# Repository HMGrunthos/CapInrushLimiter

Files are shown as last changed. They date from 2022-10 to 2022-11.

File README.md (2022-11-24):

# CapInrushLimiter
Inspiration:
* [This answer](https://electronics.stackexchange.com/questions/80365/capacitor-inrush-current/80428#80428)
* [And this question](https://electronics.stackexchange.com/questions/163939/inrush-current-limiter-design-questions-review)

Schematics:
* [Model schematic](ModelSchematic.pdf)
* [PCB schematic](CapInrushLimBB/CapInrushLimiter.pdf)

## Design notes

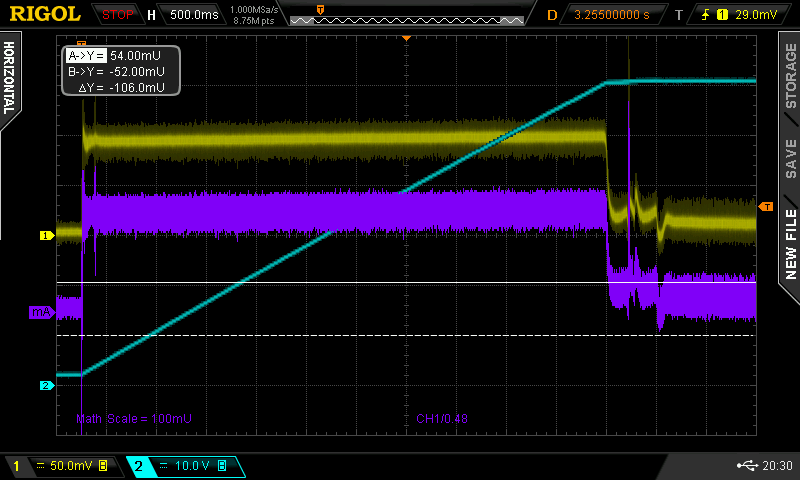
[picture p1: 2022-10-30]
ScopeTraces/RevOneCharge60V.png

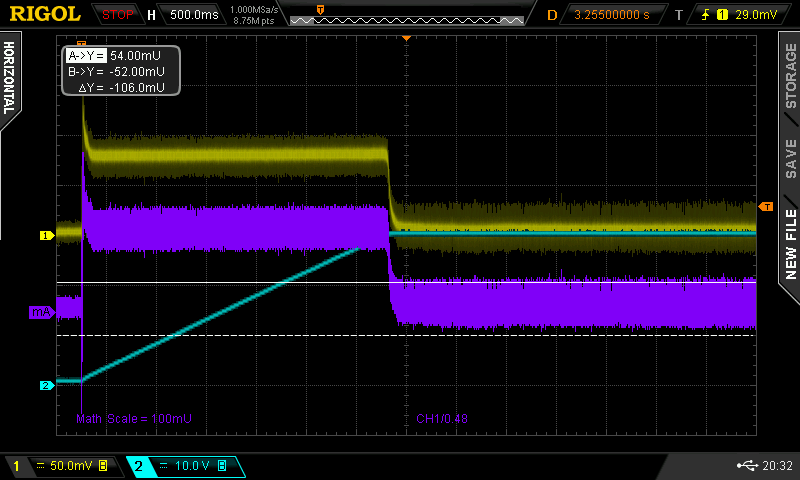
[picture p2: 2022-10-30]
ScopeTraces/RevOneCharge30V.png

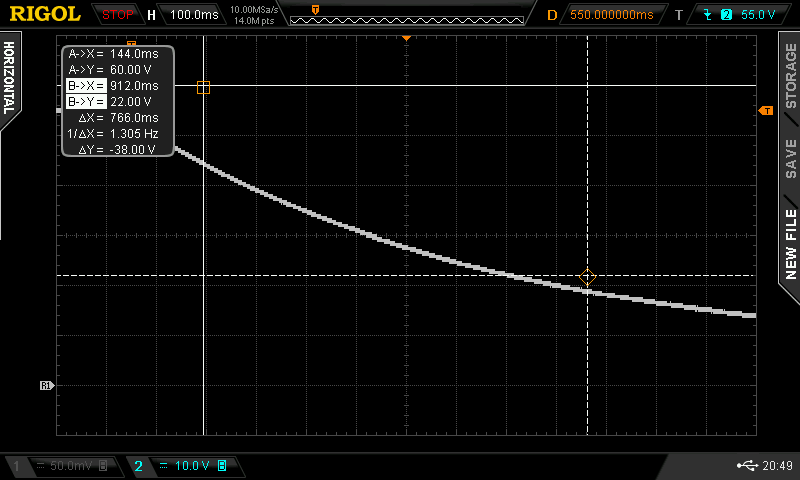
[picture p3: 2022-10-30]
ScopeTraces/RevOneDischargeThrough46R96.png

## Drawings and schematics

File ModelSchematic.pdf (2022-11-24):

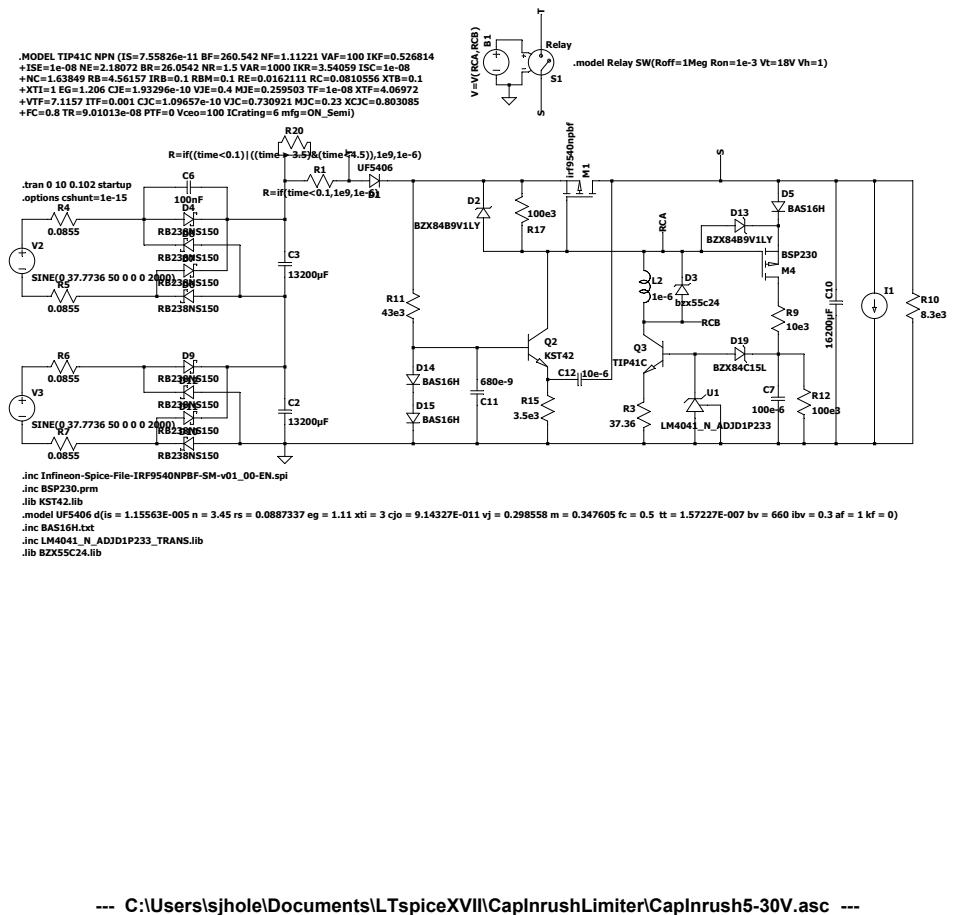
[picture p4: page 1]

Relay
.model Relay SW(Roff=1Meg Ron=1e-3 Vt=18V Vh=1)

.MODEL TIP41C NPN (IS=7.55826e-11 BF=260.542 NF=1.11221 VAF=100 IKF=0.526814
+ISE=1e-08 NE=2.18072 BR=26.0542 NR=1.5 VAR=1000 IKR=3.54059 ISC=1e-08
+NC=1.63849 RB=4.56157 IRB=0.1 RBM=0.1 RE=0.0162111 RC=0.0810556 XTB=0.1
+XTI=1 EG=1.206 CJE=1.93296e-10 VJE=0.4 MJE=0.259503 TF=1e-08 XTF=4.06972
+VTF=7.1157 ITF=0.001 CJC=1.09657e-10 VJC=0.730921 MJC=0.23 XCJC=0.803085
+FC=0.8 TR=9.01013e-08 PTF=0 Vceo=100 ICrating=6 mfg=ON_Semi)

R=if((time<0.1)|((time > 3.5)&(time<4.5)),1e9,1e-6)

.inc Infineon-Spice-File-IRF9540NPBF-SM-v01_00-EN.spi
.inc BSP230.prm
.lib KST42.lib
.model UF5406 d(is = 1.15563E-005 n = 3.45 rs = 0.0887337 eg = 1.11 xti = 3 cjo = 9.14327E-011 vj = 0.298558 m = 0.347605 fc = 0.5 tt = 1.57227E-007 bv = 660 ibv = 0.3 af = 1 kf = 0)
.inc BAS16H.txt
.inc LM4041_N_ADJD1P233_TRANS.lib
.lib BZX55C24.lib

--- C:\Users\sjhole\Documents\LTspiceXVII\CapInrushLimiter\CapInrush5-30V.asc ---

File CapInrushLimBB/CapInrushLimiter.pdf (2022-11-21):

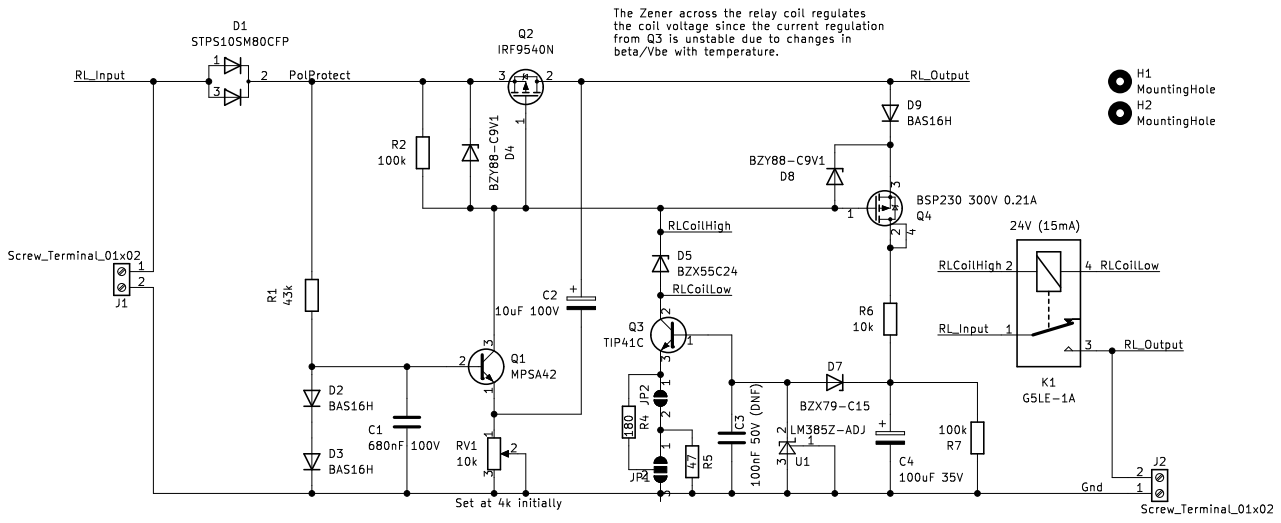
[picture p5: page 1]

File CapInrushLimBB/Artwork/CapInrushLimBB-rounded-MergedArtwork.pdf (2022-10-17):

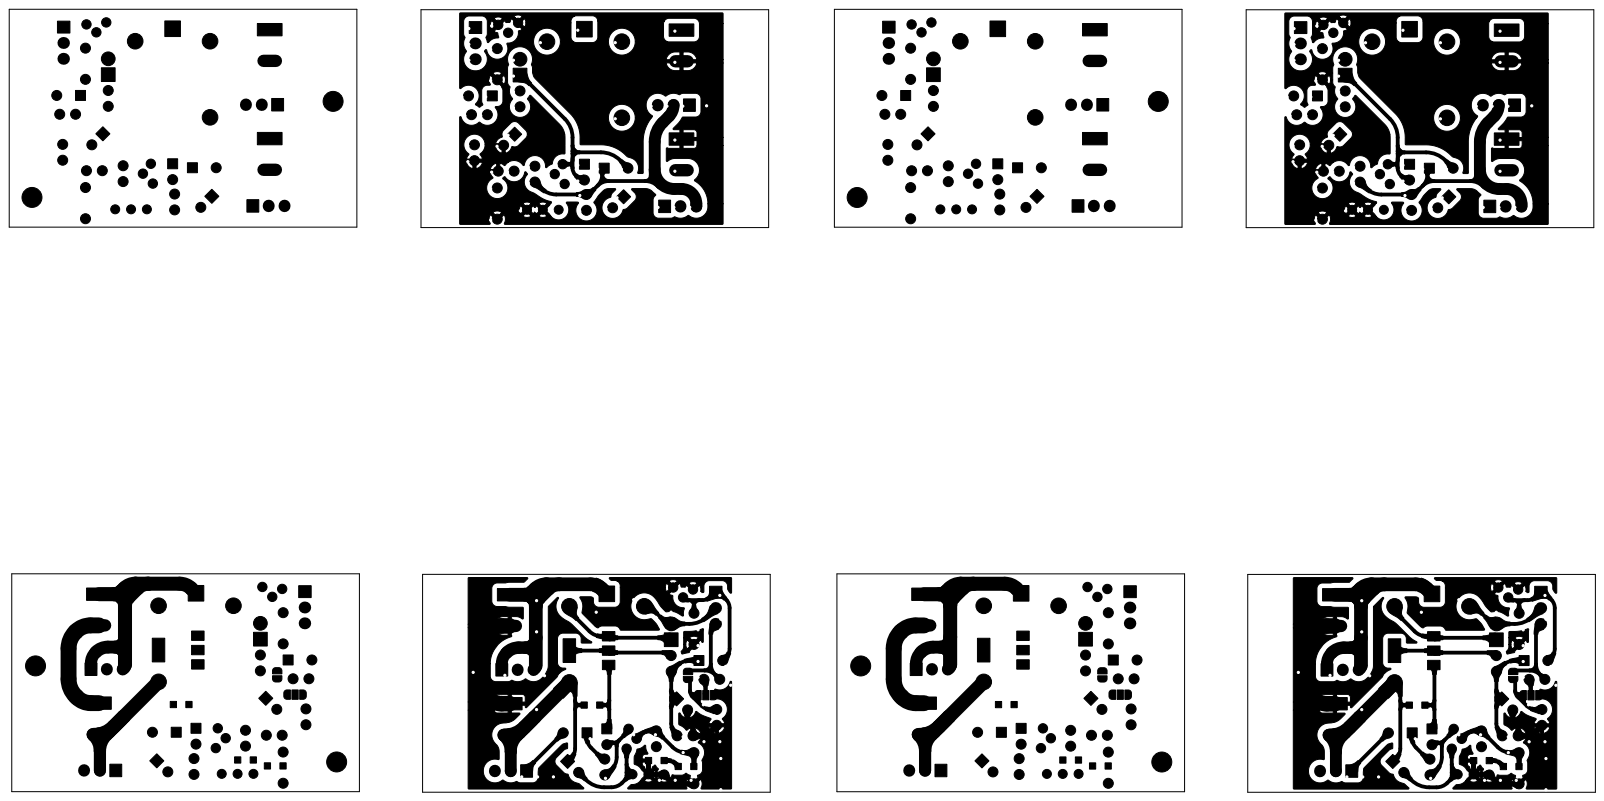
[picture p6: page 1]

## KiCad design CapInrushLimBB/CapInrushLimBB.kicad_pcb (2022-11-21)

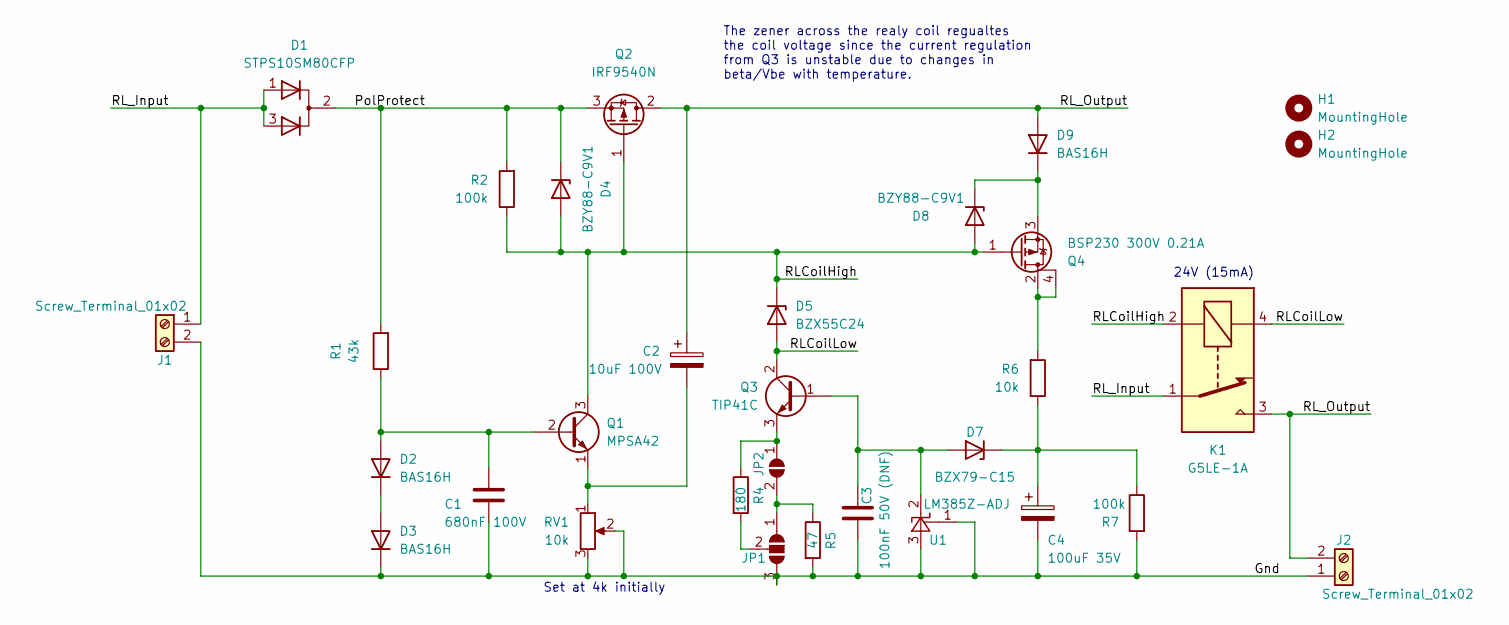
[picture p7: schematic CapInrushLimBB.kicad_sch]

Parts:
C1: 680nF 100V; C_Disc_D5.1mm_W3.2mm_P5.00mm
C2: 10uF 100V; CP_Radial_D6.3mm_P2.50mm
C3: 100nF 50V (DNF); C_Disc_D5.1mm_W3.2mm_P5.00mm
C4: 100uF 35V; CP_Radial_D6.3mm_P2.50mm
D1: STPS10SM80CFP; TO-220F-3_Vertical
D2, D3, D9: BAS16H; D_SOD-323_HandSoldering
D4: BZY88-C9V1; D_DO-35_SOD27_P3.81mm_Vertical_AnodeUp
D5: BZX55C24; D_DO-35_SOD27_P2.54mm_Vertical_KathodeUp
D7: BZX79-C15; D_DO-35_SOD27_P3.81mm_Vertical_AnodeUp
D8: BZY88-C9V1; D_DO-35_SOD27_P2.54mm_Vertical_AnodeUp
H1, H2: MountingHole; MountingHole_3.2mm_M3
J1, J2: Screw_Terminal_01x02; TerminalBlock_Altech_AK300-2_P5.00mm
JP1: SolderJumper_3_Open; SolderJumper-3_P1.3mm_Open_RoundedPad1.0x1.5mm
JP2: SolderJumper_2_Open; SolderJumper-2_P1.3mm_Open_RoundedPad1.0x1.5mm
K1: G5LE-1A; Relay_SPST-NO_Omron-G5LE-1A
Q1: MPSA42; TO-92_Inline
Q2: IRF9540N; TO-220-3_Vertical
Q3: TIP41C; TO-220-3_Vertical
Q4: BSP230 300V 0.21A; SOT-223
R1: 43k; R_Axial_DIN0207_L6.3mm_D2.5mm_P2.54mm_Vertical
R2, R7: 100k; R_Axial_DIN0207_L6.3mm_D2.5mm_P2.54mm_Vertical
R4: 180; R_Axial_DIN0207_L6.3mm_D2.5mm_P2.54mm_Vertical
R5: 47; R_Axial_DIN0207_L6.3mm_D2.5mm_P2.54mm_Vertical
R6: 10k; R_Axial_DIN0207_L6.3mm_D2.5mm_P2.54mm_Vertical
RV1: 10k; Potentiometer_Bourns_3296W_Vertical
U1: LM385Z-ADJ; TO-92_Inline

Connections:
/Gnd: C1.2, C3.1, C4.2, D3.1 (K), J1.2, J2.1, JP1.3 (B), R5.2, R7.2, RV1.2, RV1.3, U1.1 (FB), U1.3 (A)
/PolProtect: D1.2 (A), D4.1 (K), Q2.3 (S), R1.2, R2.2
/RLCoilHigh: D4.2 (A), D5.1 (K), D8.2 (A), K1.2, Q1.3 (C), Q2.1 (G), Q4.1 (G), R2.1
/RLCoilLow: D5.2 (A), K1.4, Q3.2 (C)
/RL_Input: D1.1 (K), D1.3 (K), J1.1, K1.1
/RL_Output: C2.1, D9.2 (A), J2.2, K1.3, Q2.2 (D)
unnamed: C1.1, D2.2 (A), Q1.2 (B), R1.1
unnamed: C2.2, Q1.1 (E), RV1.1
unnamed: C3.2, D7.2 (A), Q3.1 (B), U1.2 (K)
unnamed: C4.1, D7.1 (K), R6.1, R7.1
unnamed: D2.1 (K), D3.2 (A)
unnamed: D8.1 (K), D9.1 (K), Q4.3 (S)
unnamed: JP1.1 (A), JP2.2 (B), R5.1
unnamed: JP1.2 (C), R4.2
unnamed: JP2.1 (A), Q3.3 (E), R4.1
unnamed: Q4.2 (D), Q4.4 (D), R6.2

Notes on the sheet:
The zener across the realy coil regualtes the coil voltage since the current regulation from Q3 is unstable due to changes in beta/Vbe with temperature.
24V (15mA)
Set at 4k initially

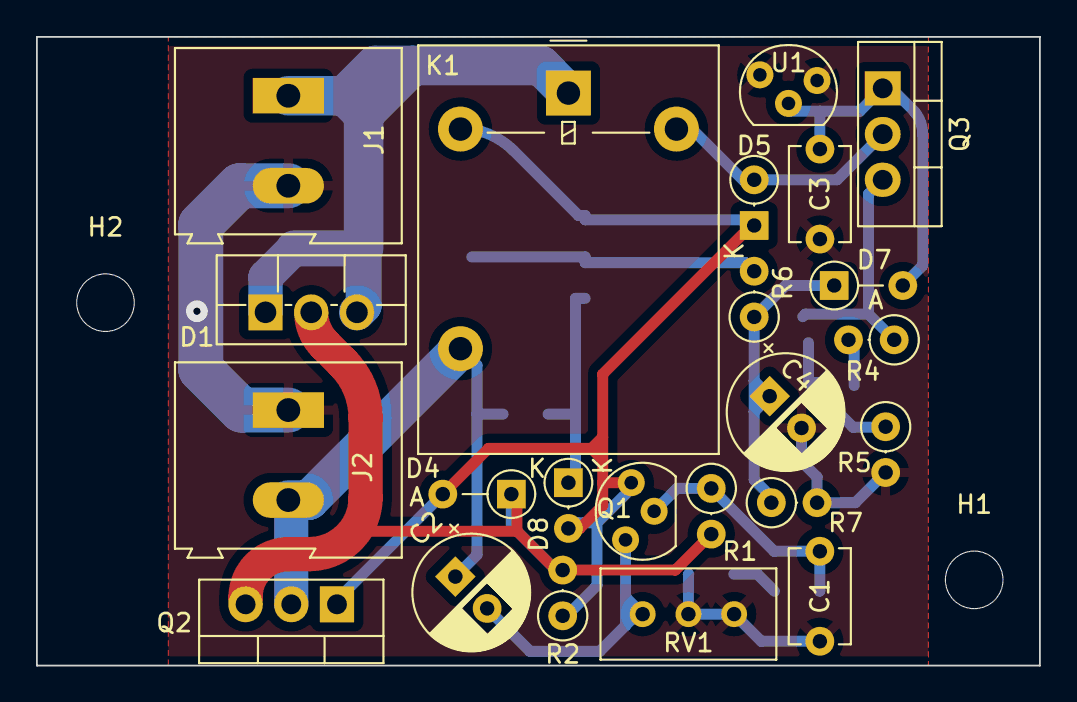
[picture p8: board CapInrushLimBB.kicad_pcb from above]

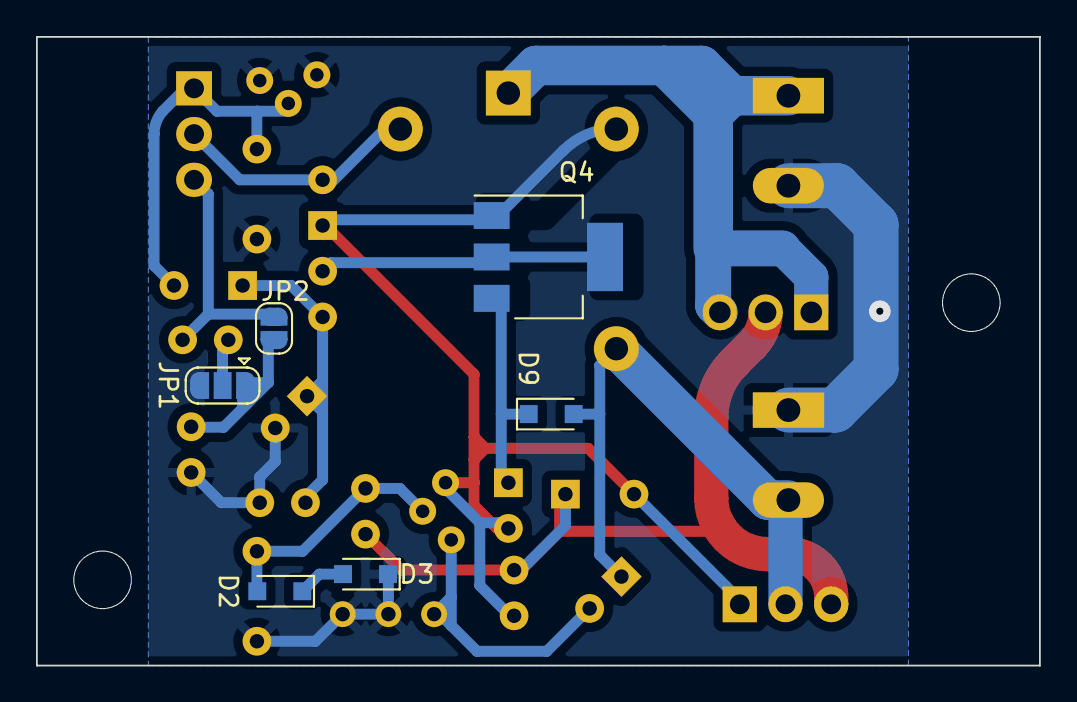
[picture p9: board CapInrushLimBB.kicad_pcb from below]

Board: 2 copper layers, 55.7 x 34.9 mm, 31 parts (6 on the bottom side), 16 nets.

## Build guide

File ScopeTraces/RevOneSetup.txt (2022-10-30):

Channel 1 was current sense resistor == 0.48 ohms
Channel 2 was voltage on capacitor bank
Math channel was channel 1 over 0.46 sense resistor

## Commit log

2022-08-29 Added reverse polarity MOSFET
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2022-08-30 Fixed gate protection on relay driver MOSFET
2022-08-30 Fixed gate protection on relay driver
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2022-09-07 Added initial version of schematic
    [CapInrushLimBB.kicad_pcb, CapInrushLimBB.kicad_sch]
2022-09-07 Connected up schematic prior to finalising component choice.
    [CapInrushLimBB.kicad_sch]
2022-09-08 Updated component values/types (no footprints yet)
    [CapInrushLimBB.kicad_sch]
2022-09-08 Tweaked layout in schematic.
    [CapInrushLimBB.kicad_sch]
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2022-09-09 Finished initial footprint assignment.
    [CapInrushLimBB.kicad_sch]
2022-09-09 Tweaked component values (names) and checked footprints.
    [CapInrushLimBB.kicad_sch]
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2022-09-11 Simplified and labelled schematic and performed work on layout.
    [CapInrushLimBB.kicad_pcb, CapInrushLimBB.kicad_sch]
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2022-09-16 Added new current limiting relay timer.
    [CapInrushLimBB.kicad_pcb]
2022-09-17 Fixed latest design - current limiting relay driver.
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2022-09-19 Updated model and schematic values.
    [CapInrushLimBB.kicad_sch]
2022-09-22 Updated values and footprints.
    [CapInrushLimBB.kicad_pcb, CapInrushLimBB.kicad_sch]
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2022-09-24 Added via linking top pour to Gnd.
    [CapInrushLimBB.kicad_pcb]
2022-09-24 Tweaked some component orientations to give space for through board connections.
    [CapInrushLimBB.kicad_pcb, CapInrushLimBB.kicad_sch]
2022-09-25 Updated relay footprint and tweaked track layout so it rounds nicley.
    [CapInrushLimBB.kicad_pcb, CapInrushLimBB.kicad_sch]
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2022-09-25 Updated silkscreen and design rules.
    [CapInrushLimBB.kicad_pcb]
2022-09-25 Tweaked tracks for a slightly better layout.
    [CapInrushLimBB.kicad_pcb]
2022-09-25 Fixed a slight clearance issue once rounded.
    [CapInrushLimBB.kicad_pcb]
2022-09-25 Added bottom ground pour and tweaked a track position to lie within it.
    [CapInrushLimBB.kicad_pcb]
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2022-09-26 Added mounting holes and adjusted board margin.
    [CapInrushLimBB.kicad_pcb]
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2022-09-26 Tweaked track widths around high current tracks.
    [CapInrushLimBB.kicad_pcb]
2022-09-27 Added rounded tracks version of PCB
    [CapInrushLimBB-rounded.kicad_pcb]
2022-09-27 Tweaked track position to equalise track clearance.
    [CapInrushLimBB.kicad_pcb]
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2022-09-28 Added artwork and tweaked Gnd track in unrounded PCB
    [CapInrushLimBB.kicad_pcb]
2022-09-28 Tweaked BJT footprint (custom) to increase clearance and tweaked track positions accordingly.
    [CapInrushLimBB.kicad_pcb, CapInrushLimBB.kicad_sch]
2022-09-28 Updated rounded tracks PCB and uploading modified TO-92 footprint (to increase clearance.)
    [CapInrushLimBB-rounded.kicad_pcb]
2022-09-29 Adding high current tracks to back mask.
    [CapInrushLimBB-rounded.kicad_pcb]
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2022-10-03 Slight track tweak following assembly.
    [CapInrushLimBB.kicad_pcb, CapInrushLimBB.kicad_sch]
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2022-10-03 Updated to remove LED reference (use two diodes) and relayed out following update.
    [CapInrushLimBB.kicad_pcb, CapInrushLimBB.kicad_sch]
2022-10-03 Increased pad sizes on the TO92 footprint and tidied up the layout a tad.
    [CapInrushLimBB.kicad_pcb]
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2022-10-10 Updated rounded tracks version of updates for low voltage use.
    [CapInrushLimBB-rounded.kicad_pcb]
2022-10-11 Added solder mask region.
    [CapInrushLimBB-rounded.kicad_pcb]
2022-10-13 Modified schematic to support low voltage operation with 24V relay and updated board layout.
    [CapInrushLimBB.kicad_pcb, CapInrushLimBB.kicad_sch]
2022-10-13 Updated PCB layout of lower voltage capable inrush limiter.
    [CapInrushLimBB-rounded.kicad_pcb, CapInrushLimBB.kicad_pcb]
2022-10-13 Added lower voltage tollerant model and started tweaking PCB layout to move pass element somewhere where it can be heat sunk.
    [CapInrushLimBB.kicad_pcb]
2022-10-13 Updated footprints in schematic and layed out tracks to make pass element accessable from the side of the board.
    [CapInrushLimBB.kicad_pcb, CapInrushLimBB.kicad_sch]
2022-10-13 Updated layout and rounded tracks version.
    [CapInrushLimBB-rounded.kicad_pcb, CapInrushLimBB.kicad_pcb]
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2022-10-15 Changed the reference type, changed current set resistor strategy and updated PCB.
    [CapInrushLimBB-rounded.kicad_pcb, CapInrushLimBB.kicad_pcb, CapInrushLimBB.kicad_sch]
2022-10-16 Relayed out relay timer/regulator section to reduce track lengths.
    [CapInrushLimBB.kicad_pcb, CapInrushLimBB.kicad_sch]
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2022-10-17 Added comment text on default setting for timer pot.
    [CapInrushLimBB.kicad_sch]
2022-10-17 Updated rounded tracks version.
    [CapInrushLimBB-rounded.kicad_pcb]
2022-10-17 Updated to match rounded version.
    [CapInrushLimBB.kicad_pcb]
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2022-11-10 Updated values of relay current limiter resistors.
    [CapInrushLimBB-rounded.kicad_pcb, CapInrushLimBB.kicad_pcb, CapInrushLimBB.kicad_sch]
2022-11-16 Updating model, schematic and PCB to remote cap. on the relay timer ref. and to fit a zener across the relay coil.
    [CapInrushLimBB-rounded.kicad_pcb, CapInrushLimBB.kicad_pcb, CapInrushLimBB.kicad_sch]
2022-11-17 Updating model, schematic and PCB to remove cap. on the relay timer ref. and to fit a zener across the relay coil.
    [CapInrushLimBB-rounded.kicad_pcb, CapInrushLimBB.kicad_pcb, CapInrushLimBB.kicad_sch]
2022-11-18 Added comments on setting timing pot and why I'm using a zener across the relay coil.
    [CapInrushLimBB.kicad_sch]
2022-11-19 Switched to lower rated 24V zener and tidied up dependent models (already on a separate branch.)
    [CapInrushLimBB.kicad_pcb, CapInrushLimBB.kicad_sch]
2022-11-19 Updated current limit components.
    [CapInrushLimBB.kicad_pcb, CapInrushLimBB.kicad_sch]
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2022-11-21 Added schematic PDF and fixed typos in schematic sheet.
    [CapInrushLimBB.kicad_sch]
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
